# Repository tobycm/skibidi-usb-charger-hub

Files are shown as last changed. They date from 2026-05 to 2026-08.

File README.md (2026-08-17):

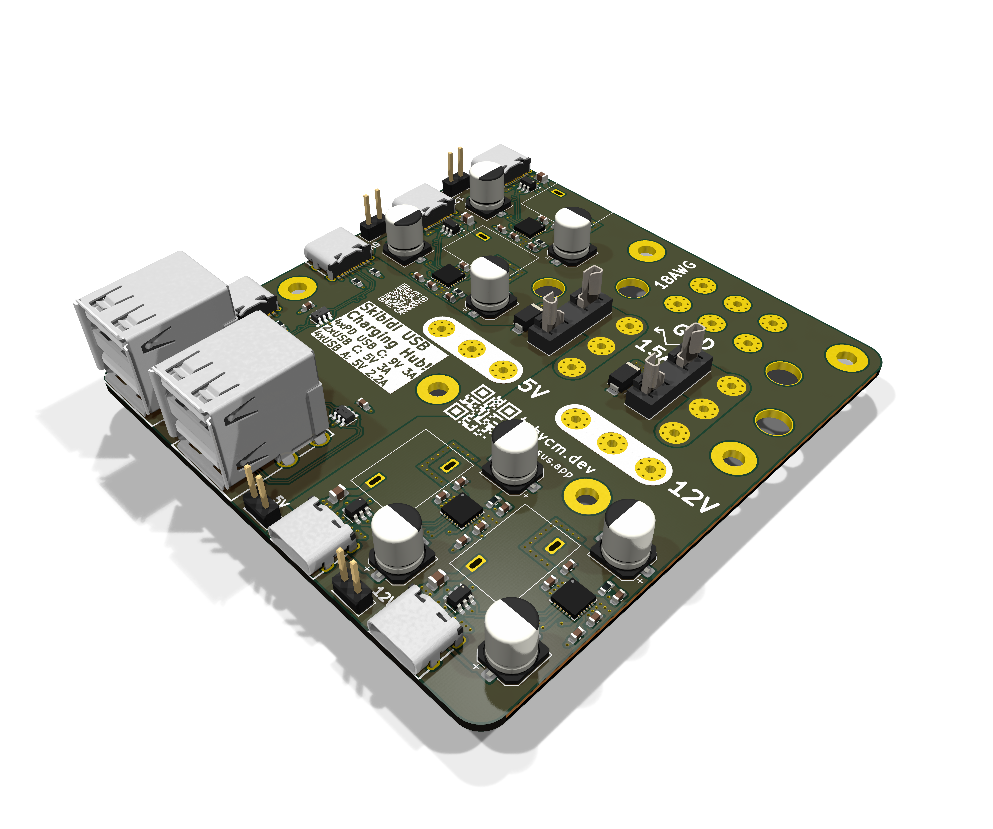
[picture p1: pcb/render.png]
render


# skibidi-usb-charger-hub

a very skibidi usb charger hub. powered using an old PC PSU with 12V and 5V, providing:

- 4 x PD USB C: 9V 3A
- 2 x USB C: 5V 3A
- 4 x USB A: 5V 2.2A

<hr>
<p align="center">
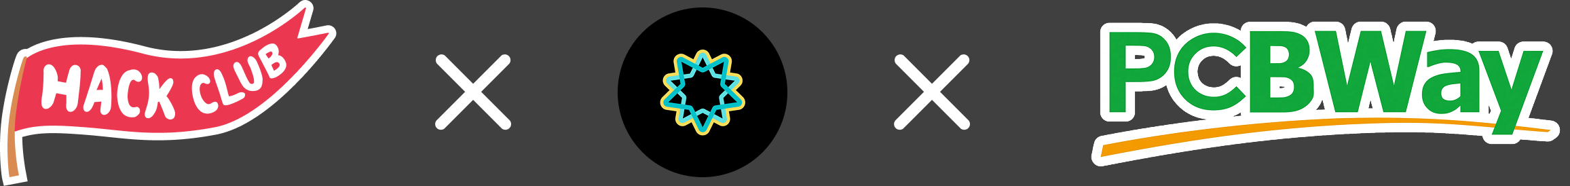
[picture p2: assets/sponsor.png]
    <br>
    <strong>This project was partly sponsored by PCBWay and Hack Club</strong>
    <p><a href="https://www.pcbway.com/">PCBWay</a> is a PCB manufacturing company that provides high-quality PCB services. I am happy to collaborate with them to bring this project to life. My experience with PCBWay:</p>
    <ul>
        <li>They double check your designs before production, making sure there aren't silly mistakes that got past your DRC.</li>
        <li>Their customer service is fast and very helpful. I needed to modify my PCBA order and got a response in the same day.</li>
        <li>PCBA orders doesn't have extended component fees like JLCPCB, making it cheaper in some cases. Parts can be source from many places, like LCSC, DigiKey, etc.</li>
        <li>Lots of different colours for PCBs (thinking of a pink PCB for next project :3c)</li>
    </ul>
    <details>
        <summary>Pictures:</summary>
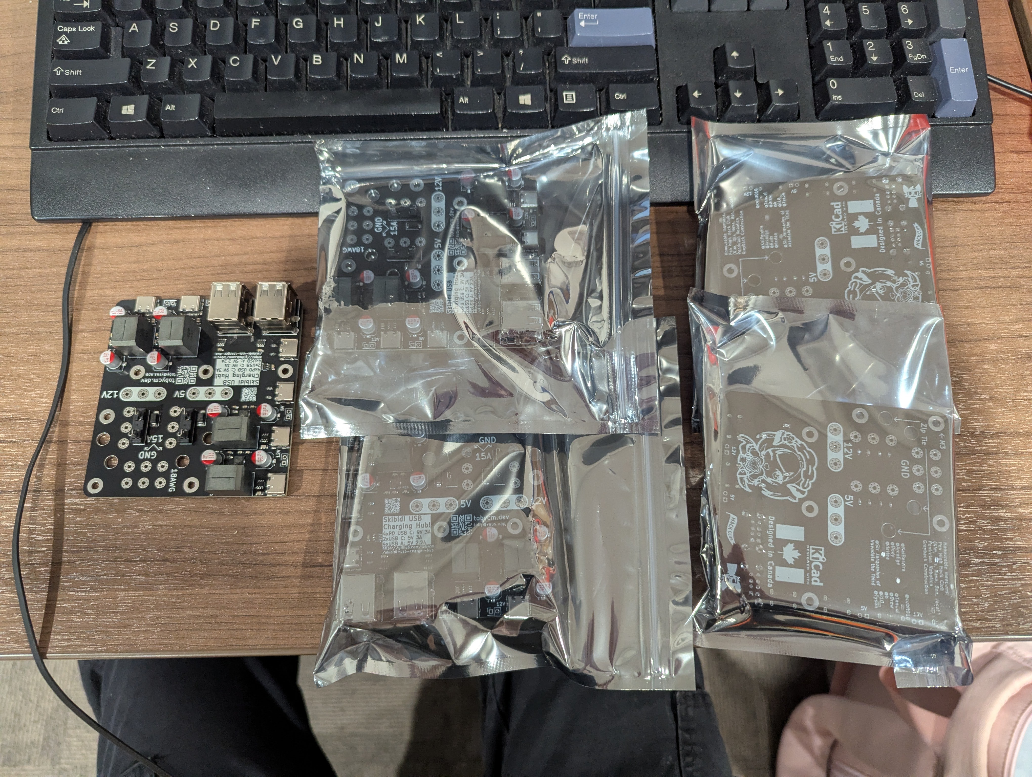
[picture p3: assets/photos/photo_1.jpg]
        
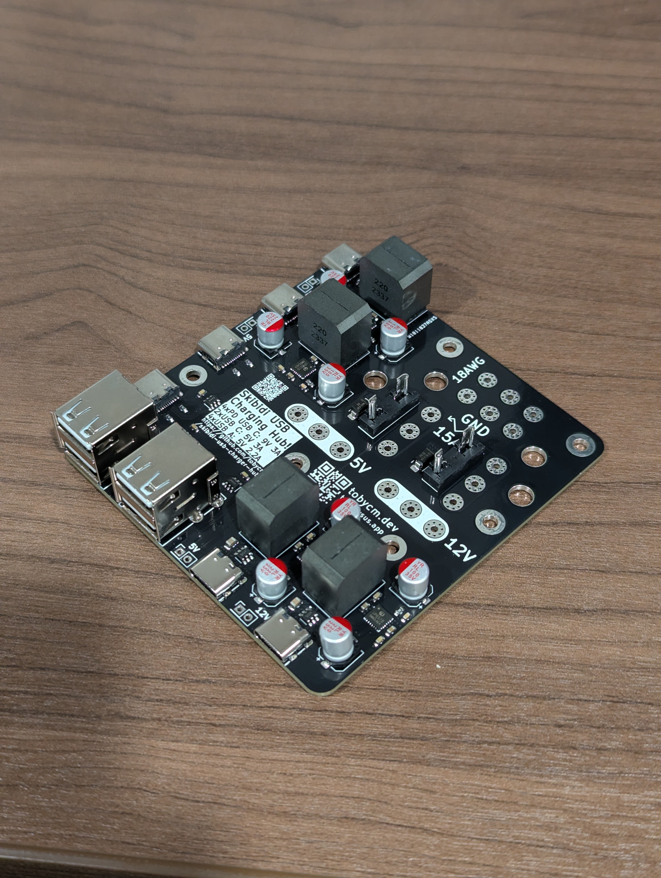
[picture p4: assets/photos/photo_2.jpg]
        
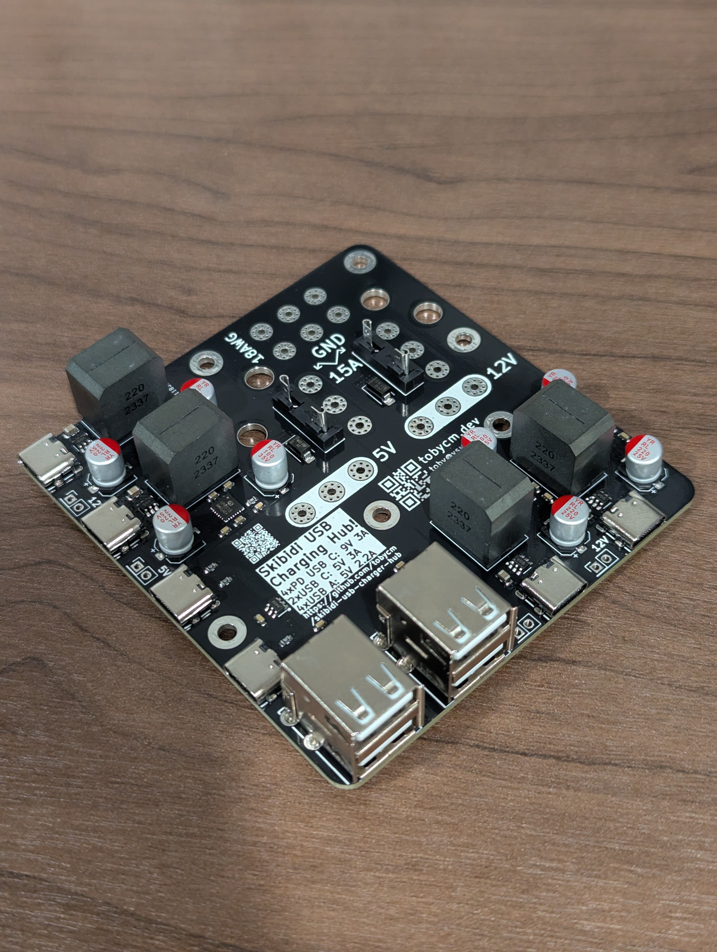
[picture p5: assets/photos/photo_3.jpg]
        
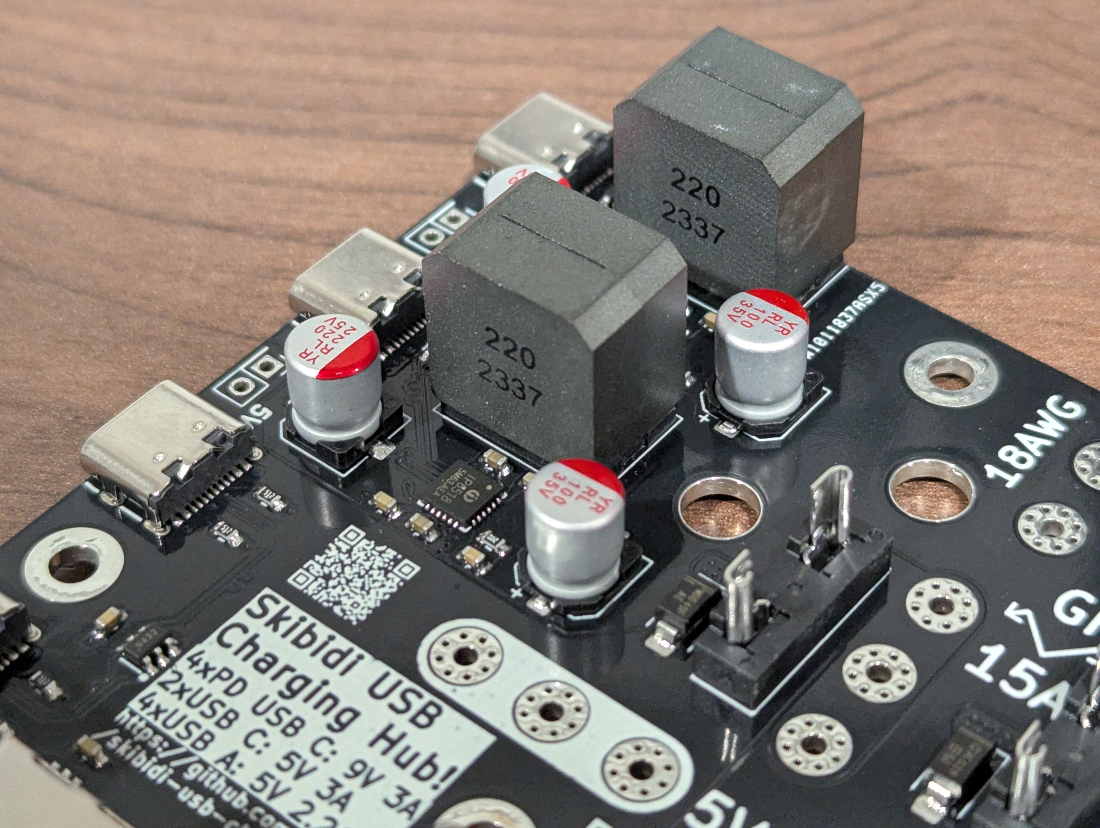
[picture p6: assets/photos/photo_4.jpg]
        
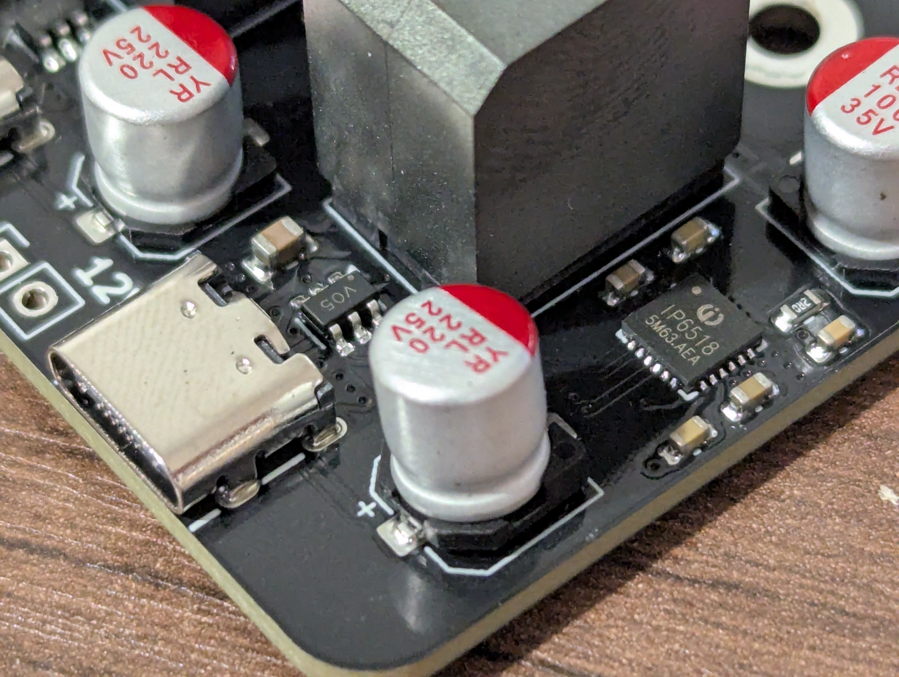
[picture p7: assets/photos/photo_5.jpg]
        
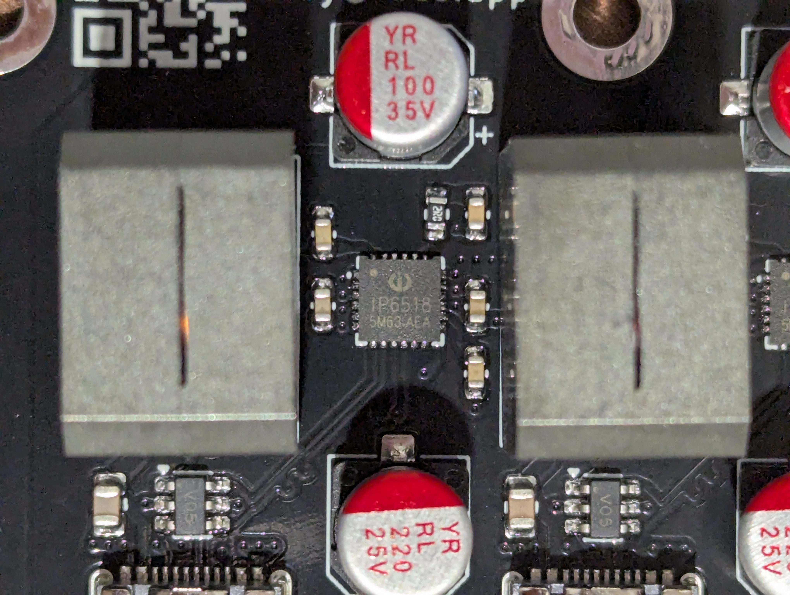
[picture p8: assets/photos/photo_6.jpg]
        
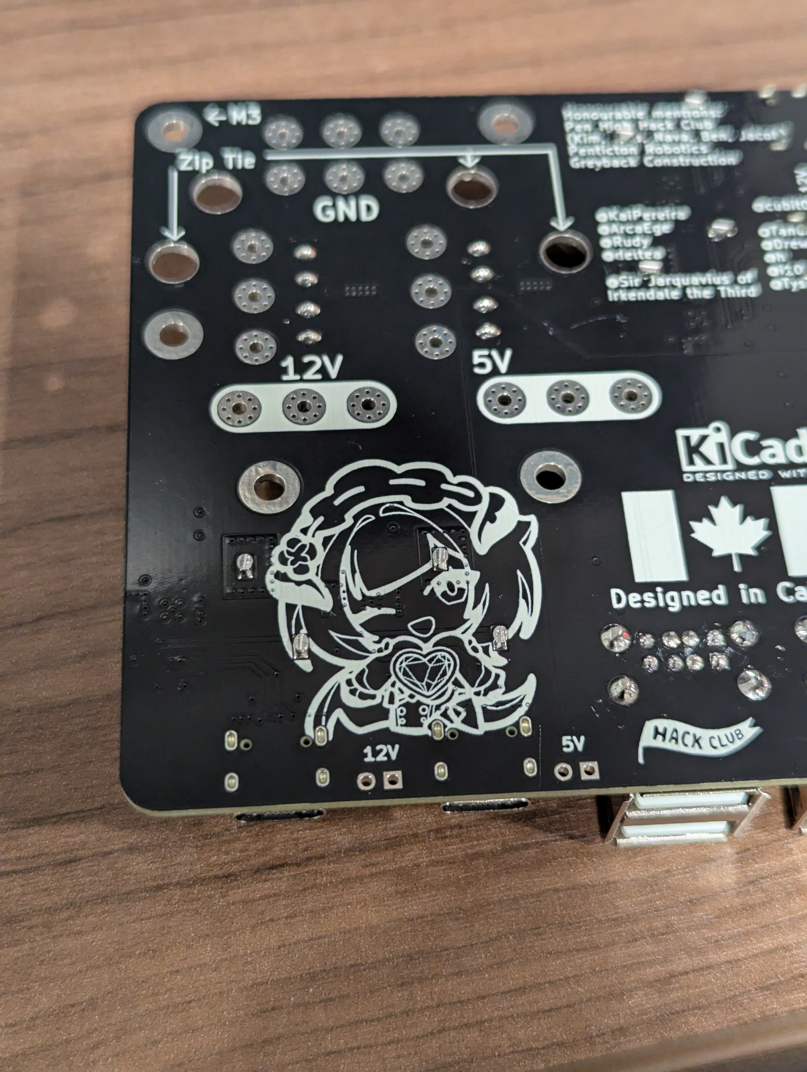
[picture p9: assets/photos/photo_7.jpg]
        
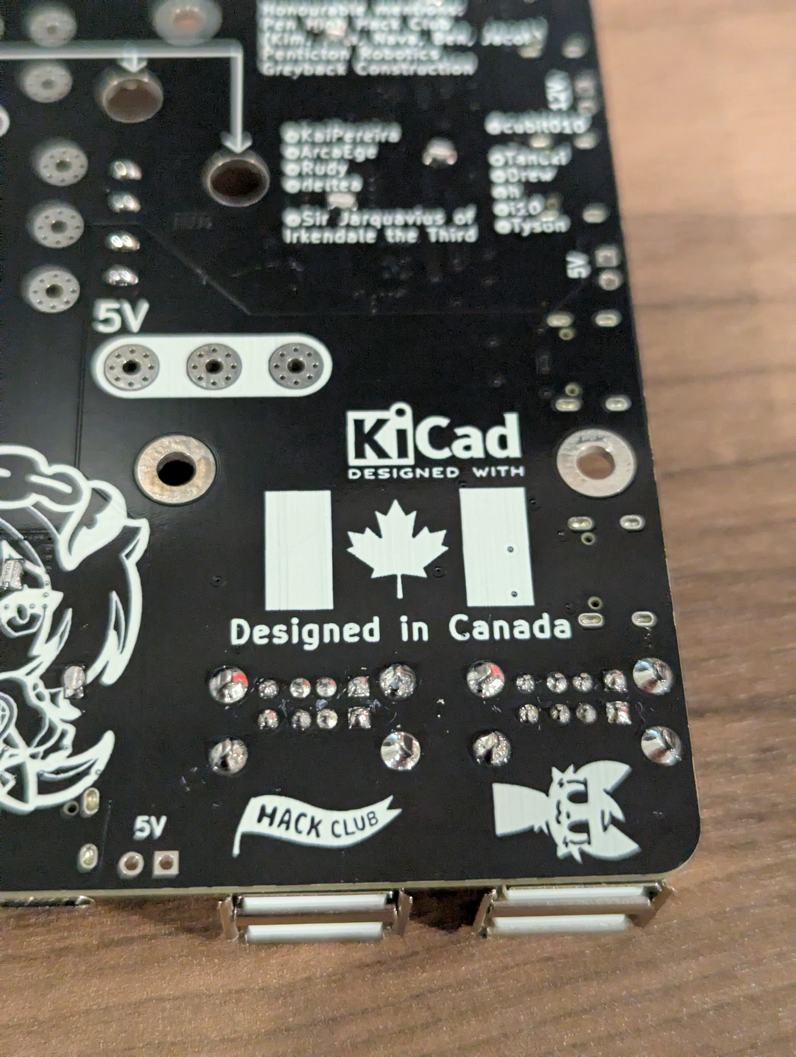
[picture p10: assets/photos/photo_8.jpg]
        
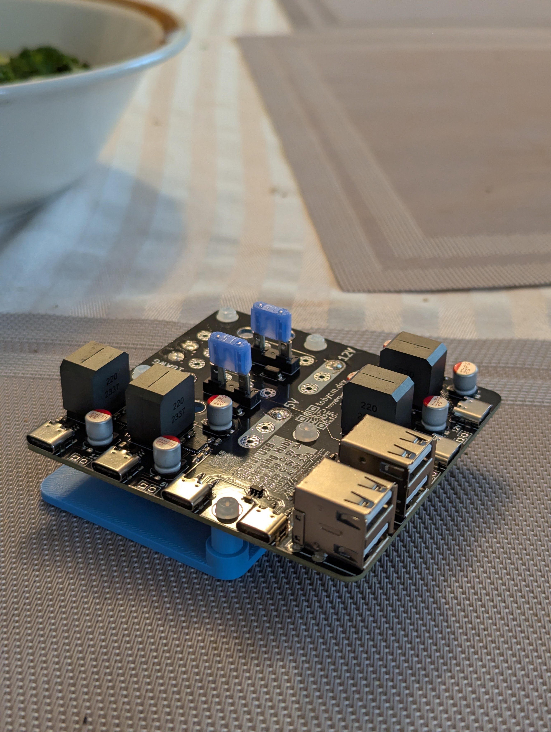
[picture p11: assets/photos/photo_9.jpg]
        
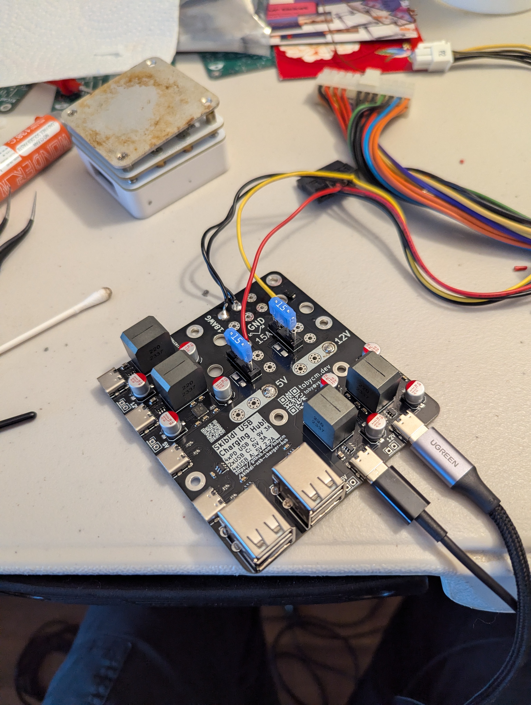
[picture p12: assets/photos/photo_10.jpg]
        
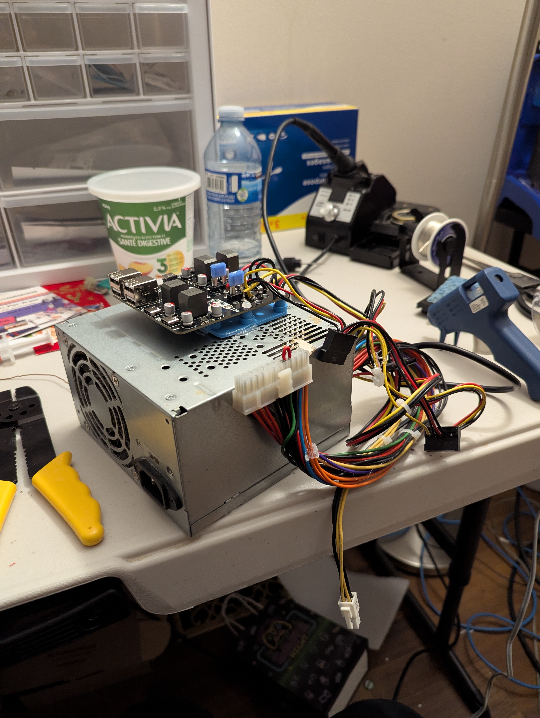
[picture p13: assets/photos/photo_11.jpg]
        
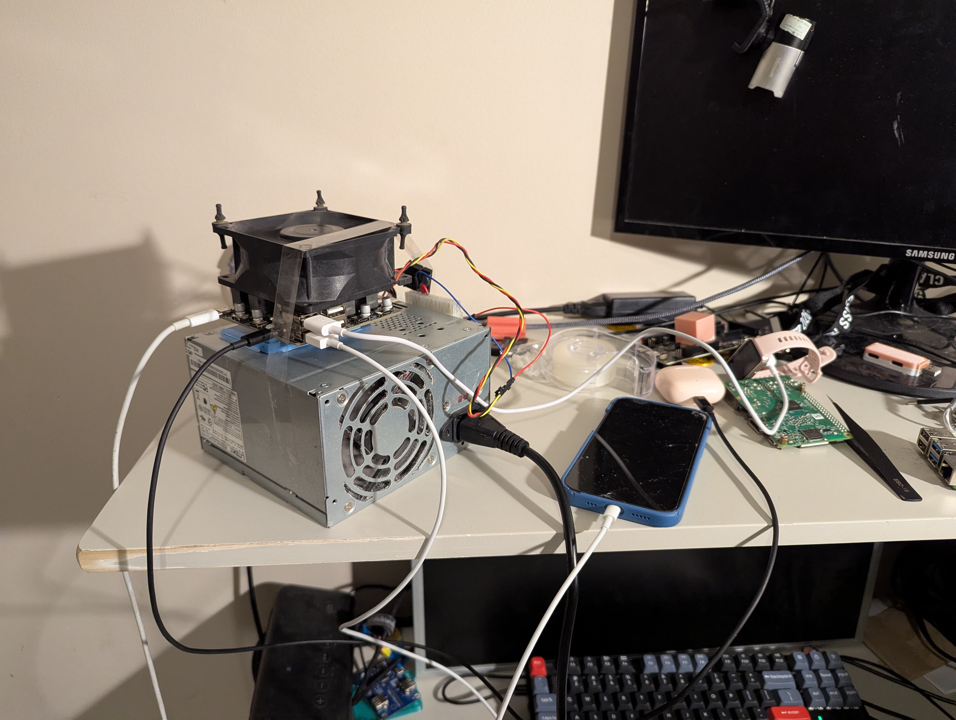
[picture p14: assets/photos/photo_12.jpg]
        
    </details>
    <p>---------</p>
    <p><a href="https://hackclub.com/">Hack Club</a> is the world's largest nonprofit movement of teenagers making cool projects. This project was partly funded by the <a href="https://fallout.hackclub.com/">Fallout</a> program from Hack Club!</p>

</p>
<hr>

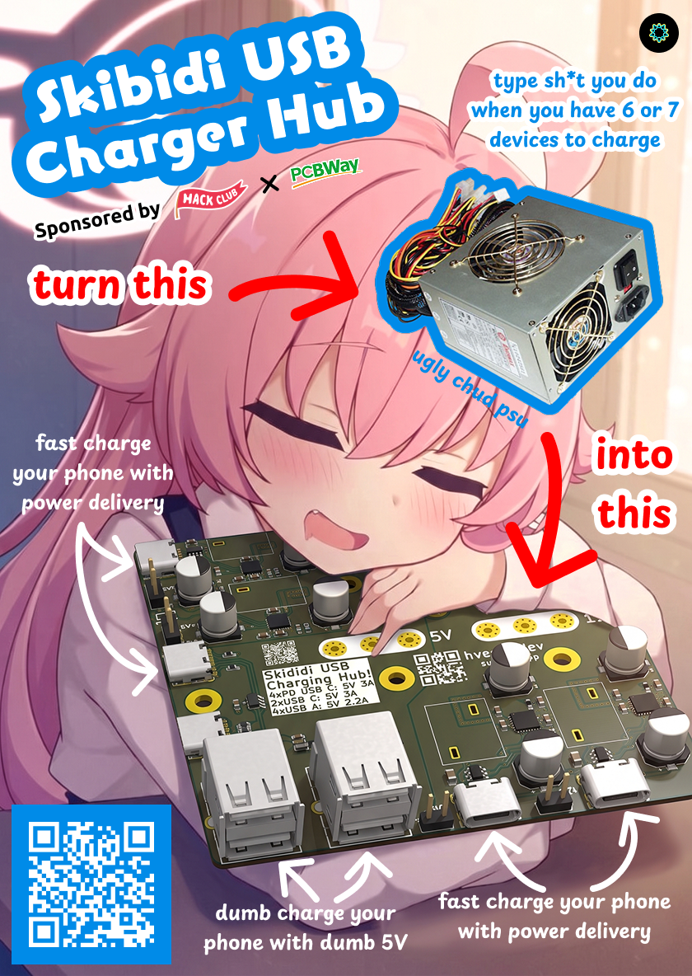
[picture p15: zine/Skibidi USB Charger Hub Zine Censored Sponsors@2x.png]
zine


## PSU

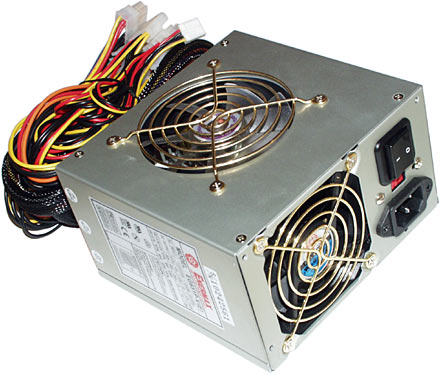
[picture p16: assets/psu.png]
psu

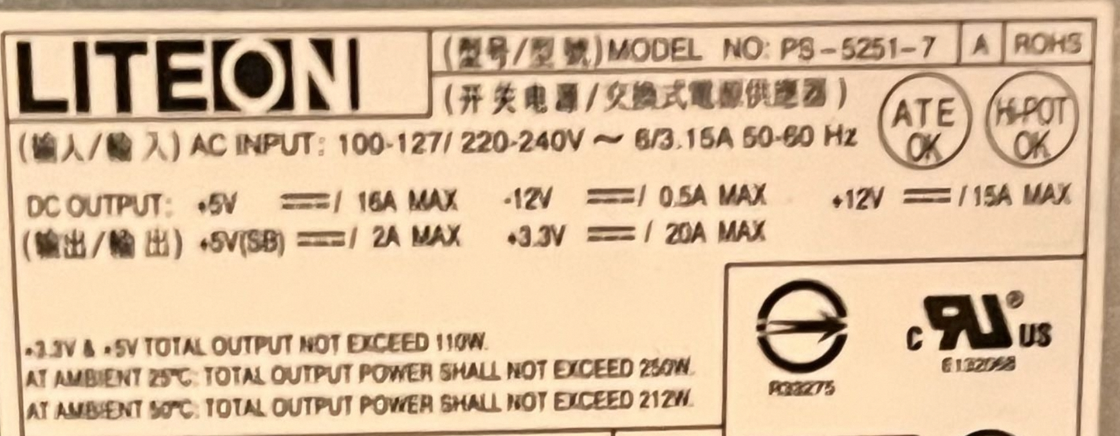
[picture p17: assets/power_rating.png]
power rating


5V 16A | 12V 15A

## PCB Renders

[OnShape model](https://cad.onshape.com/documents/76d0eacda952f7a16601ad60/w/6632ab11f69bcce9ea203d2d/e/41ef5674a500edea83bbca98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)

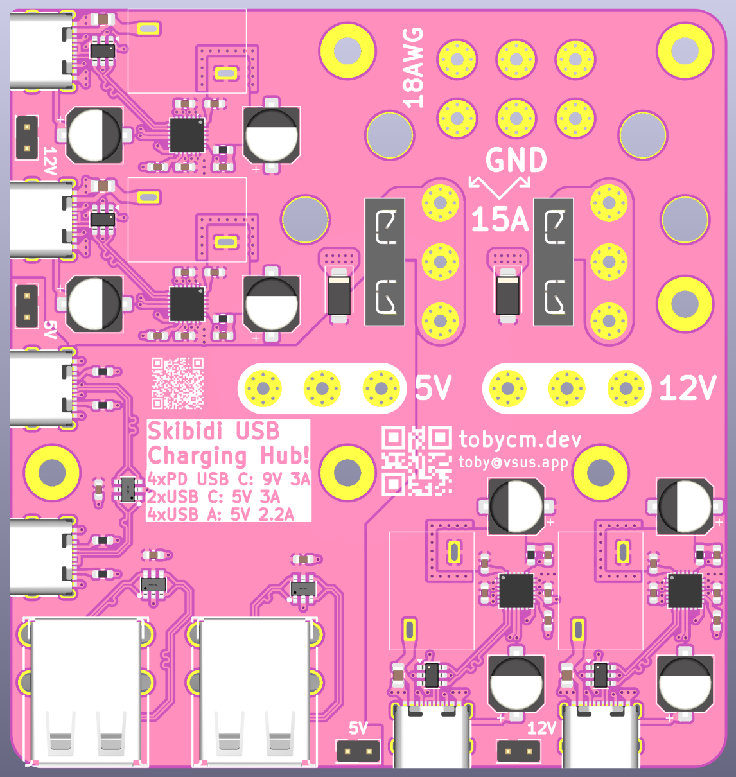
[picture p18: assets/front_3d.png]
front 3d pcb


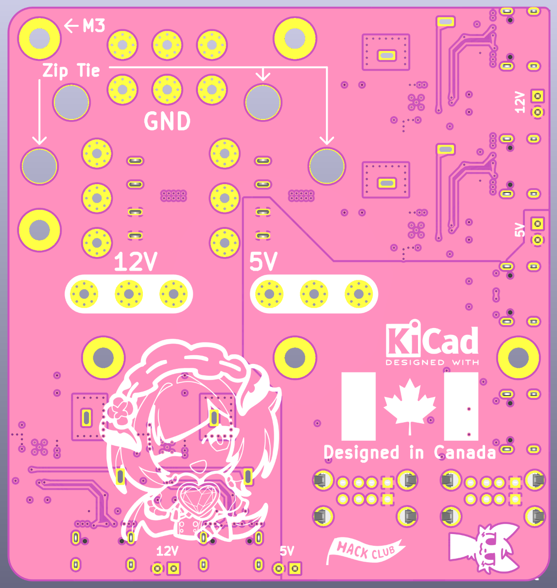
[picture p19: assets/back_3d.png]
back 3d pcb


## End notes

Made with <3 by @tobycm

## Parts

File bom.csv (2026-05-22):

Description | Quantity | Part # | Unit price | Extended Price USD | Link
100n『 』Unpolarized capacitor『 』SMD_2terminal_chip_molded | 11 | CL10B104KB8NNNC | $0.006 | 0.33
1n『 』Unpolarized capacitor『 』SMD_2terminal_chip_molded | 4 | CL10B102KB8NNNC | $0.008 | 0.16
100u『 』Polarized capacitor『 』capacitor/SMD/elec_round_polarized | 4 | R6RL035101C077MH0XX | $0.278 | 5.56
1u『 』Unpolarized capacitor『 』SMD_2terminal_chip_molded | 8 | CL10B105KA8NNNC | $0.013 | 0.52
220u『 』Polarized capacitor『 』capacitor/SMD/elec_round_polarized | 4 | R6RL025221C077MH0XX | $0.278 | 5.56
22u『 』Unpolarized capacitor『 』SMD_2terminal_chip_molded | 4 | CL21A226MAYNNNE | $0.063 | 1.26
SMAJ5.0A『 』400W unidirectional Transient Voltage Suppressor, 5.0Vr, SMA(DO-214AC) | 1 | SMAJ5.0A | $0.046 | 0.23
SMAJ15A『 』400W unidirectional Transient Voltage Suppressor, 15.0Vr, SMA(DO-214AC) | 1 | SMAJ15A | $0.081 | 0.41
Fuse『 』Fuse | 2 | XF-505P | $0.136 | 1.36
USB_C_Receptacle_USB2.0_14P『 』USB 2.0-only 14P Type-C Receptacle connector | 6 | TYPE-C 16PIN 2MD(073) | $0.148 | 4.44
Conn_02x01『 』Generic connector, double row, 02x01, this symbol is compatible with counter-clockwise, top-bottom and odd-even numbering schemes., script generated (kicad-library-utils/schlib/autogen/connector/)『 』connector/pin_header_socket | 4 |  |  | 0
22u『 』Inductor | 4 | DEP1410-220 | $1.855 | 37.1
5.1k『 』Resistor『 』SMD_2terminal_chip_molded | 4 | FRC0603F5101TS | $0.003 | 0.06
2『 』Resistor『 』SMD_2terminal_chip_molded | 4 | FRC0603J2R0 TS | $0.003 | 0.06
IP6518 | 4 | IP6518 | $1.769 | 35.38
USBLC6-4SC6『 』Very low capacitance ESD protection diode, 4 data-line, SOT-23-6『 』package/gullwing | 4 | USBLC6-4SC6-ES | $0.028 | 0.56
NDP5102SE | 3 | NDP5102SE | $0.069 | 1.04
AF SS-JB17.6 | 2 | AF SS-JB17.6 | $0.256 | 2.56
4 Layer PCB | 5 | PCB | 19.11 | 95.55
PCBWay Shipping | 1 |  | 43 | 43 | https://www.pcbway.com/
150pcs White Nylon Hex Screw M2 M2.5 M3 M4 M5 Bolt Nut Standoff Spacer Kit with Plastic Box Corrosion Resistant | 0 | 1005002059852181 | 4.07 | 0
Aliexpress Shipping | 0 | Aliexpress Shipping | 2.04 | 0
 |  | Total: |  | 235.13

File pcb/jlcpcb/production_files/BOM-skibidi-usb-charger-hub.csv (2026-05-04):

Comment | Designator | Footprint | LCSC | Quantity
100n | C1,C10,C15,C18,C2,C23,C26,C3,C31,C34,C7 | C_0603_1608Metric | C1591 | 11
100u | C12,C20,C28,C4 | CP_Elec_6.3x7.7 | C53237859 | 4
1n | C11,C19,C27,C35 | C_0603_1608Metric | C1588 | 4
1u | C13,C14,C21,C22,C29,C30,C5,C6 | C_0603_1608Metric | C29936 | 8
2 | R5,R6,R7,R8 | R_0603_1608Metric | C2907139 | 4
220u | C16,C24,C32,C8 | CP_Elec_6.3x7.7 | C53237860 | 4
22u | L1,L2,L3,L4 | DEP1410-220 | C2962793 | 4
22u | C17,C25,C33,C9 | C_0805_2012Metric | C602037 | 4
5.1k | R1,R2,R3,R4 | R_0603_1608Metric | C2907044 | 4
AF SS-JB17.6 | USB1,USB2 | USB-A-TH_AF-SS-JB17.6 | C456021 | 2
Fuse | F1,F2 | FUSE-TH_XF-505P | C843270 | 2
IP6518 | U10,U12,U14,U16 | QFN-24_L4.0-W4.0-P0.50-BL-EP2.6 | C181688 | 4
NDP5102SE | U3,U6,U9 | SOT-23-6_L2.9-W1.6-P0.95-LS2.9-BL | C7420597 | 3
SMAJ15A | D2 | D_SMA | C908769 | 1
SMAJ5.0A | D1 | D_SMA | C113952 | 1
USBLC6-4SC6 | U11,U13,U15,U17 | SOT-23-6 | C5180279 | 4
USB_C_Receptacle_USB2.0_14P | J1,J2,J3,J4,J5,J6 | USB-C-SMD_TYPE-C-16PIN-2MD-073 | C2765186 | 6
Conn_02x01 | J9 | PinHeader_2x01_P2.54mm_Vertical |  | 1
Conn_02x01 | J8 | PinHeader_2x01_P2.54mm_Vertical |  | 1
Conn_02x01 | J7 | PinHeader_2x01_P2.54mm_Vertical |  | 1
Conn_02x01 | J10 | PinHeader_2x01_P2.54mm_Vertical |  | 1

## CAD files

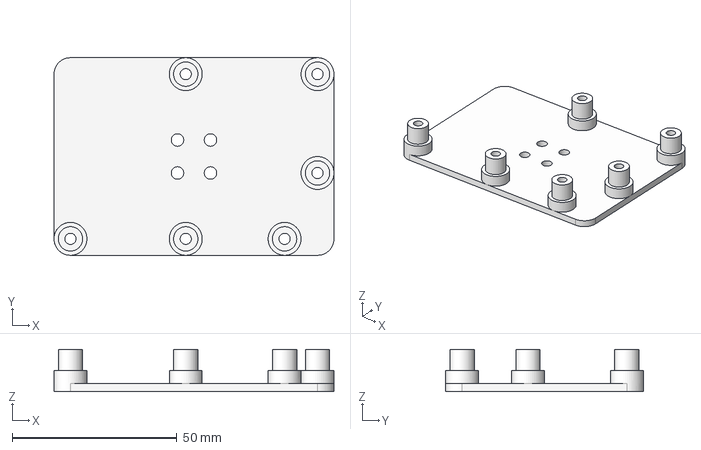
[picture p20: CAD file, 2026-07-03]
cad/mounting plate.step
85.0 x 60.0 x 12.8 mm

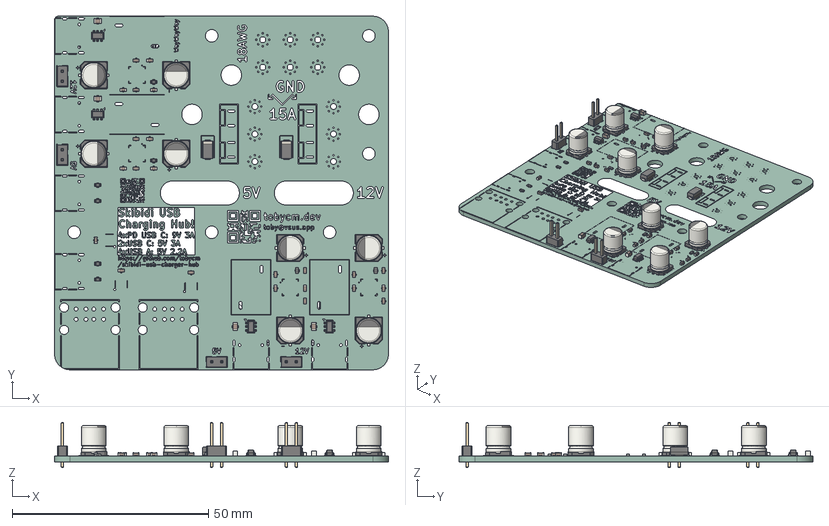
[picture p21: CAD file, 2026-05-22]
cad/pcb.step
85.0 x 90.0 x 11.5 mm
C_0603_1608Metric x 23
R_0603_1608Metric x 8
CP_Elec_6.3x7.7 x 8
PinHeader_2x01_P2.54mm_Vertical x 4
C_0805_2012Metric x 4
SOT-23-6 x 4
D_SMA x 2
skibidi-usb-charger-hub_silkscreen x 2
skibidi-usb-charger-hub_PCB

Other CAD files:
cad/mounting plate.3mf

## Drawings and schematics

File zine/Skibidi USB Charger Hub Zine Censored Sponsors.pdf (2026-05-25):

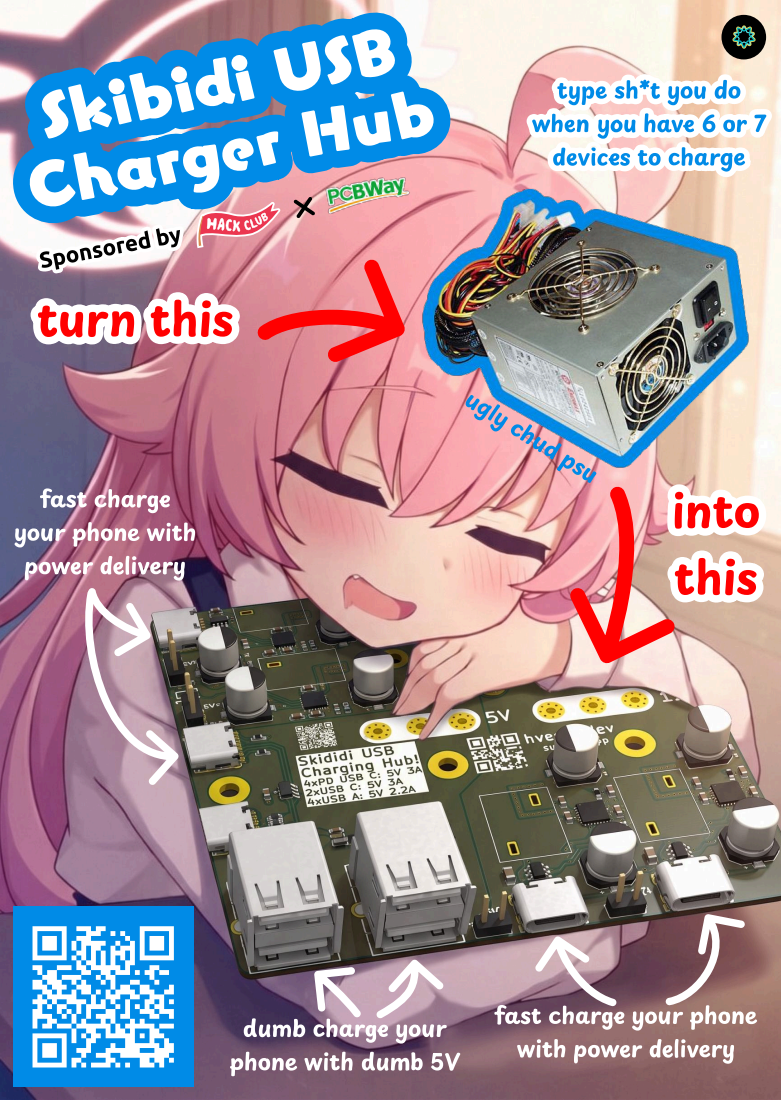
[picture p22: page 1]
Sponsored by; turn this; this

type sh*t you do
when you have 6 or 7
devices to charge

ugly chud psu into

fast charge
your phone with
power delivery

dumb charge your
phone with dumb 5V

fast charge your phone
with power delivery

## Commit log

2026-04-30 finished schematic and pcb woohoo!
    [power.kicad_sch, skibidi-usb-charger-hub.kicad_pcb, skibidi-usb-charger-hub.kicad_sch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]
2026-04-30 add gerbers
    [BOM-skibidi-usb-charger-hub.csv, skibidi-usb-charger-hub.kicad_pcb, skibidi-usb-charger-hub.kicad_sch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]
2026-05-04 update art + gerbers + readme
    [BOM-skibidi-usb-charger-hub.csv, pcb.step, power.kicad_sch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]
2026-05-05 add pcbway gerber + back render + names on pcb back
    [skibidi-usb-charger-hub.kicad_pcb]
2026-05-22 add zine and mounting plate
    [mounting plate.step, pcb.step]
2026-05-22 add bom
    [bom.csv]
2026-05-22 add link to bom
    [bom.csv]
2026-07-03 update mounting plate cad
    [mounting plate.3mf, mounting plate.step]
